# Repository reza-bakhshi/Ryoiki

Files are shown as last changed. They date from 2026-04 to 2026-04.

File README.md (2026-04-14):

# Ryoiki

⚠️ **THIS PROJECT IS UNDER ACTIVE DEVELOPMENT AND TESTING
DO NOT MANUFACTURE OR USE THE HARDWARE WITHOUT YOUR OWN VERIFICATION**

---

## Images

### TOP

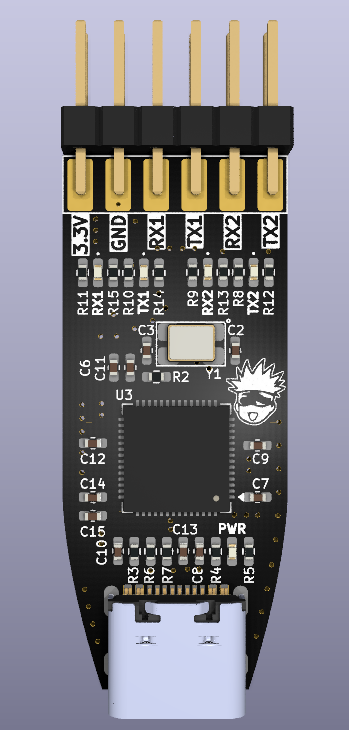
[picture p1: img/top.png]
top


### BOTTOM

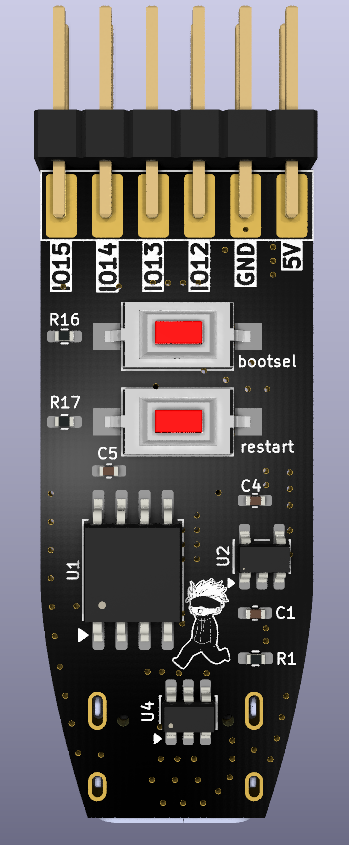
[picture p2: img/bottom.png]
bottom


---

## Overview

**Ryoiki** is an RP2040-based multi-purpose USB protocol bridge designed for embedded development workflows where USB ports are limited and multiple hardware interfaces are required.

This project is inspired by:

* BlueTag
* Bus Pirate
* pico-uart-bridge

The device is designed to:

* Bridge multiple protocols (UART / I²C / SPI → USB)
* Reduce the number of USB ports used
* Act as a compact RP2040 header-style board with limited pins when needed

---

## Project Goal

During embedded Linux development, using multiple USB-to-serial converters quickly consumes all available USB ports and creates cable clutter.

**Ryoiki** solves this by providing multiple interfaces over a single USB connection in a compact and flexible form factor.

---

## Current Status

| Interface | Status |
| --- | --- |
| UART | ✅ Working |
| I²C | 🚧 In development (currently disabled) |
| SPI | 🚧 In development (currently disabled) |

This is a prototype and both hardware and firmware are still under validation.

---

## Firmware

The current firmware is based on my fork of the pico-uart-bridge project.

When connected to a Linux system, the device enumerates as two independent CDC interfaces:

```text
/dev/ttyACM0  
/dev/ttyACM1
```

Each interface provides access to one UART channel.

### Features

* Auto-baudrate detection
* No manual baudrate configuration required
* Plug-and-play on Linux

---

## Hardware Design

The hardware is designed based on:

* RP2040 Zero form factor
* Official Raspberry Pi RP2040 hardware design guidelines

### Design Targets

* Compact size
* Low component count
* High flexibility for future features
* Header-style usability in external projects

### Hardware Features

* RP2040 microcontroller
* USB device interface
* Dual UART ports
* Dedicated **RX/TX status LEDs** for each UART

Designed with **KiCad**.

---

## Use Cases

* Embedded Linux development
* Multi-device serial debugging
* Compact USB lab tool
* Future multi-protocol debugging interface

---

## Future Plans

| Feature | Description | Status |
| --- | --- | --- |
| I²C Bridge | USB to I²C interface | 🚧 In development |
| SPI Bridge | USB to SPI interface | 🚧 In development |
| Multi-protocol Debug Mode | Bus Pirate / BlueTag-like functionality | 🧩 Planned |

---

## Development Notes

* Hardware revisions are expected
* Firmware is evolving rapidly
* Not production-ready

---

## Repository Structure

```text
/hardware   → KiCad design files  
/firmware   → RP2040 firmware  
/docs       → Documentation  
```

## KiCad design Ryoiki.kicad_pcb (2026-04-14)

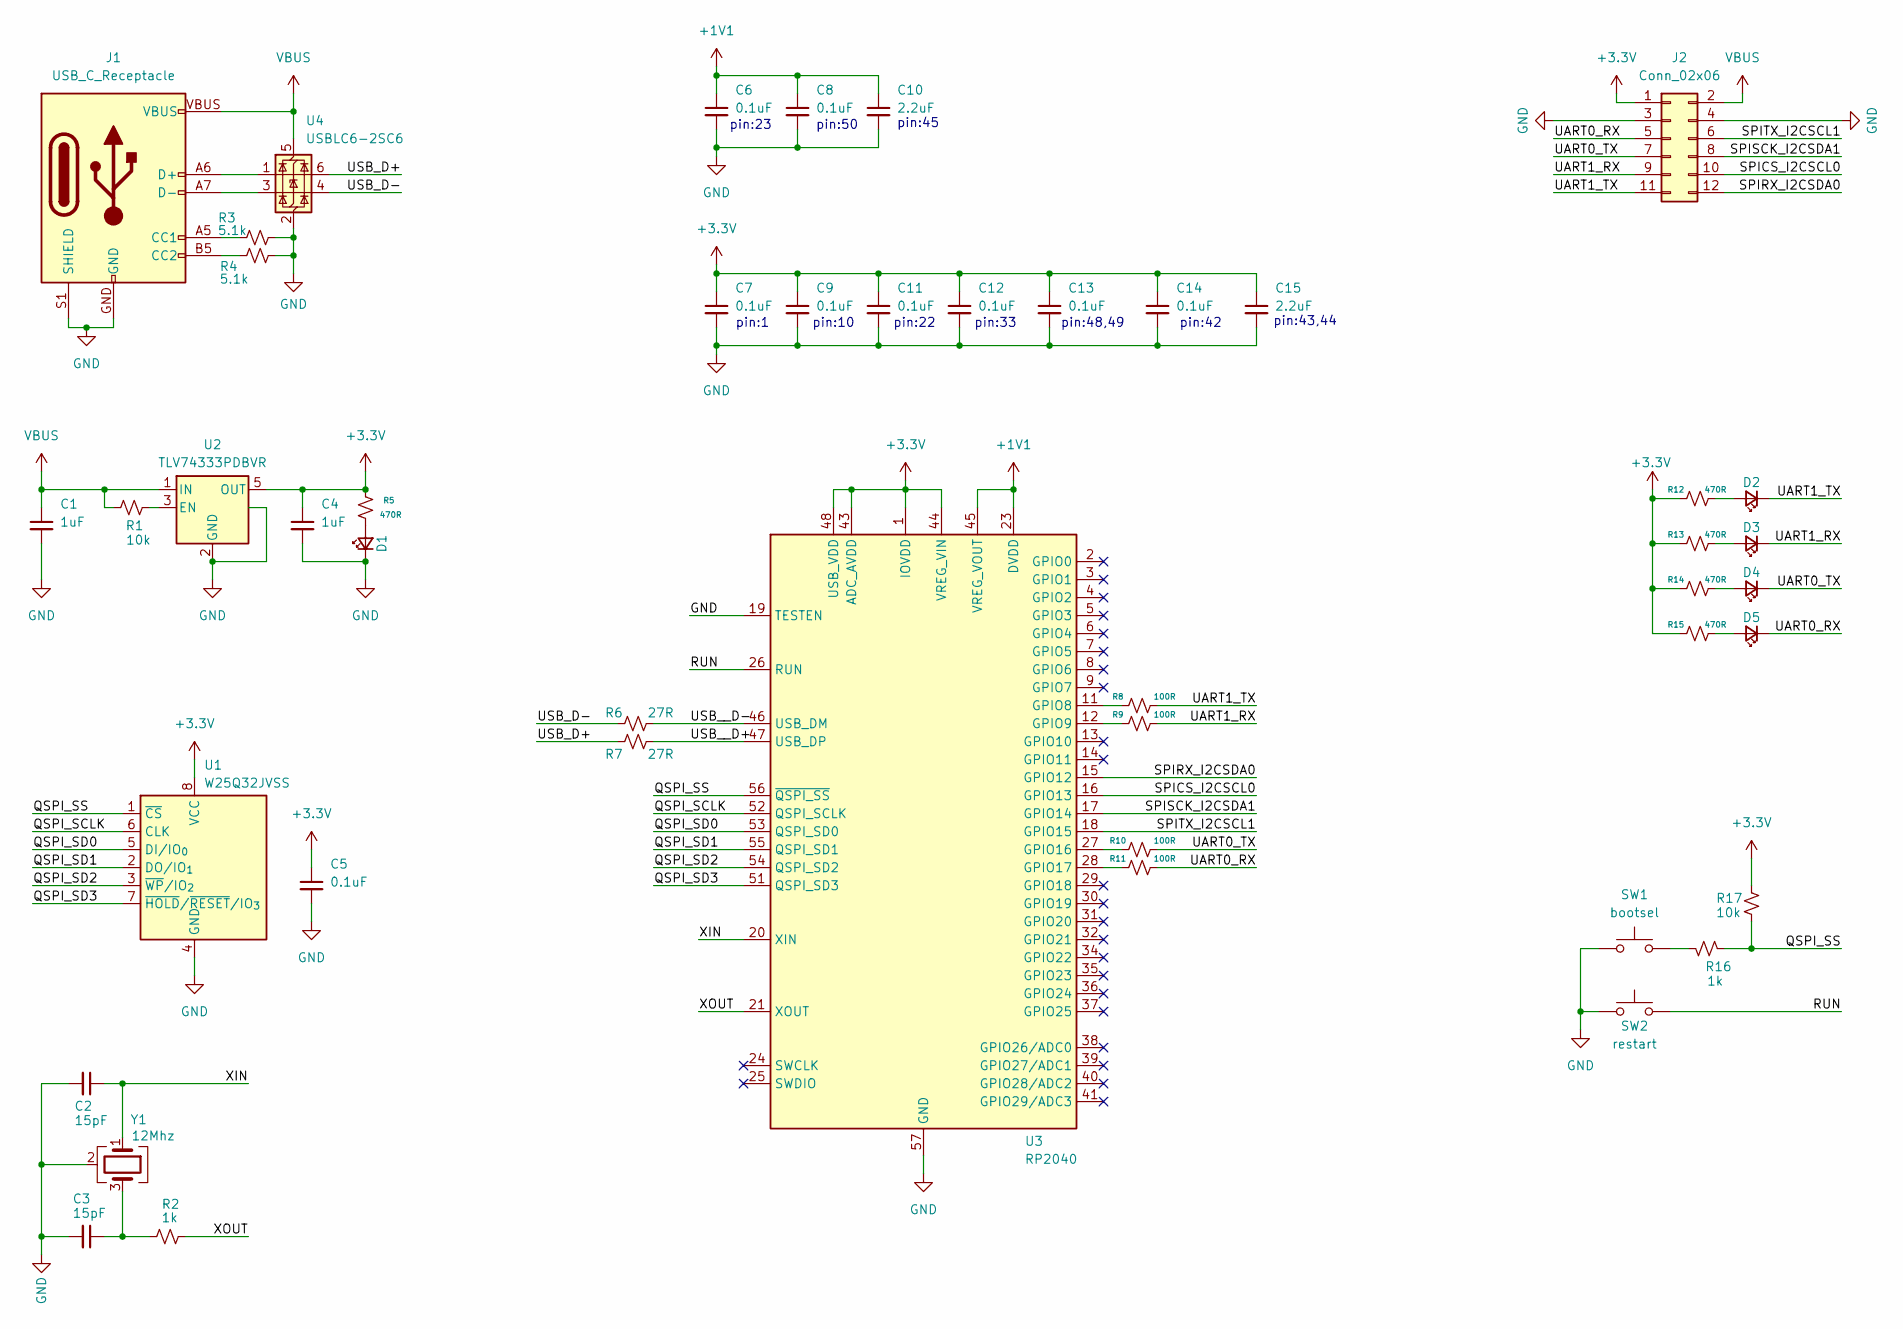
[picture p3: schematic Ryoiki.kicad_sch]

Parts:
C1, C4: 1uF; C_0402_1005Metric_Pad0.74x0.62mm_HandSolder; Voltage 25V
C2, C3: 15pF; C_0402_1005Metric_Pad0.74x0.62mm_HandSolder
C5, C6, C7, C8, C9, C11, C12, C13, C14: 0.1uF; C_0402_1005Metric_Pad0.74x0.62mm_HandSolder; Voltage 25V
C10, C15: 2.2uF; C_0402_1005Metric_Pad0.74x0.62mm_HandSolder; Voltage 25V
D1: PWR; LED_0402_1005Metric_Pad0.77x0.64mm_HandSolder
D2: TX2; LED_0402_1005Metric_Pad0.77x0.64mm_HandSolder
D3: RX2; LED_0402_1005Metric_Pad0.77x0.64mm_HandSolder
D4: TX1; LED_0402_1005Metric_Pad0.77x0.64mm_HandSolder
D5: RX1; LED_0402_1005Metric_Pad0.77x0.64mm_HandSolder
J1: USB_C_Receptacle; USB-C_16
J2: Conn_02x06; PinHeader_2x06_SMD_P2.54mm_Horizontal
R1, R17: 10k; R_0402_1005Metric_Pad0.72x0.64mm_HandSolder
R2, R16: 1k; R_0402_1005Metric_Pad0.72x0.64mm_HandSolder
R3, R4: 5.1k; R_0402_1005Metric_Pad0.72x0.64mm_HandSolder
R5, R12, R13, R14, R15: 470R; R_0402_1005Metric_Pad0.72x0.64mm_HandSolder
R6, R7: 27R; R_0402_1005Metric_Pad0.72x0.64mm_HandSolder
R8, R9, R10, R11: 100R; R_0402_1005Metric_Pad0.72x0.64mm_HandSolder
SW1: bootsel; SW_SPST_CK_RS282G05A3
SW2: restart; SW_SPST_CK_RS282G05A3
U1: W25Q32JVSS; SOIC-8_5.3x5.3mm_P1.27mm
U2: TLV74333PDBVR; SOT-23-5
U3: RP2040; QFN-56-1EP_7x7mm_P0.4mm_EP3.2x3.2mm
U4: USBLC6-2SC6; SOT-23-6
Y1: 12Mhz; Crystal_SMD_4Pin

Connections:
+1V1: C6.1, C8.1, C10.1, U3.23 (DVDD), U3.45 (VREG_VOUT), U3.50 (DVDD)
+3.3V: C4.1, C5.1, C7.1, C9.1, C11.1, C12.1, C13.1, C14.1, C15.1, J2.1, R5.1, R12.1, R13.1, R14.1, R15.1, R17.1, U1.8 (VCC), U2.5 (OUT), U3.1 (IOVDD), U3.10 (IOVDD), U3.22 (IOVDD), U3.33 (IOVDD), U3.42 (IOVDD), U3.43 (ADC_AVDD), U3.44 (VREG_VIN), U3.48 (USB_VDD), U3.49 (IOVDD)
/QSPI_SCLK: U1.6 (CLK), U3.52 (QSPI_SCLK)
/QSPI_SD0: U1.5 (DI/IO_{0}), U3.53 (QSPI_SD0)
/QSPI_SD1: U1.2 (DO/IO_{1}), U3.55 (QSPI_SD1)
/QSPI_SD2: U1.3 (~WP/IO_{2}), U3.54 (QSPI_SD2)
/QSPI_SD3: U1.7 (~HOLD/~RESET/IO_{3}), U3.51 (QSPI_SD3)
/QSPI_SS: R16.2, R17.2, U1.1 (~CS), U3.56 (~QSPI_SS)
/RUN: SW2.2, U3.26 (RUN)
/SPICS_I2CSCL0: J2.10, U3.16 (GPIO13)
/SPIRX_I2CSDA0: J2.12, U3.15 (GPIO12)
/SPISCK_I2CSDA1: J2.8, U3.17 (GPIO14)
/SPITX_I2CSCL1: J2.6, U3.18 (GPIO15)
/UART0_RX: D5.1 (K), J2.5, R11.2
/UART0_TX: D4.1 (K), J2.7, R10.2
/UART1_RX: D3.1 (K), J2.9, R9.2
/UART1_TX: D2.1 (K), J2.11, R8.2
/USB_D+: R7.1, U4.6 (I/O1)
/USB_D-: R6.1, U4.4 (I/O2)
/USB__D+: R7.2, U3.47 (USB_DP)
/USB__D-: R6.2, U3.46 (USB_DM)
/XIN: C2.1, U3.20 (XIN), Y1.1
/XOUT: R2.2, U3.21 (XOUT)
GND: C1.2, C2.2, C3.2, C4.2, C5.2, C6.2, C7.2, C8.2, C9.2, C10.2, C11.2, C12.2, C13.2, C14.2, C15.2, D1.1 (K), J1.GND, J1.S1 (SHIELD), J1.S2 (SHIELD), J1.S3 (SHIELD), J1.S4 (SHIELD), J2.3, J2.4, R3.2, R4.2, SW1.1, SW2.1, U1.4 (GND), U2.2 (GND), U2.4 (NC), U3.19 (TESTEN), U3.57 (GND), U4.2 (GND), Y1.2 (G), Y1.4 (G)
unnamed: C3.1, R2.1, Y1.3
unnamed: D1.2 (A), R5.2
unnamed: D2.2 (A), R12.2
unnamed: D3.2 (A), R13.2
unnamed: D4.2 (A), R14.2
unnamed: D5.2 (A), R15.2
unnamed: J1.A5 (CC1), R3.1
unnamed: J1.B5 (CC2), R4.1
unnamed: J1.A6 (D+), J1.B6 (D+), U4.1 (I/O1)
unnamed: J1.A7 (D-), J1.B7 (D-), U4.3 (I/O2)
unnamed: R16.1, SW1.2
unnamed: R1.1, U2.3 (EN)
unnamed: R8.1, U3.11 (GPIO8)
unnamed: R9.1, U3.12 (GPIO9)
unnamed: R10.1, U3.27 (GPIO16)
unnamed: R11.1, U3.28 (GPIO17)
VBUS: C1.1, J1.VBUS, J2.2, R1.2, U2.1 (IN), U4.5 (VBUS)

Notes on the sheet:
pin:42
pin:1
pin:23
pin:45
pin:50
pin:22
pin:48,49
pin:33
pin:43,44
pin:10

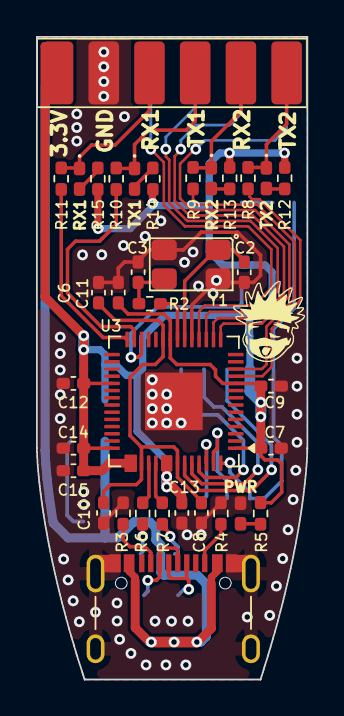
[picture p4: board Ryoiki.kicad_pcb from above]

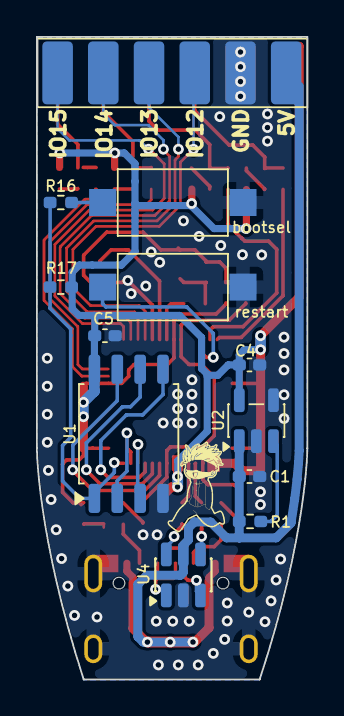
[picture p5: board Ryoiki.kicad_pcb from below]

Board: 2 copper layers, 15.0 x 35.7 mm, 46 parts (11 on the bottom side), 41 nets.

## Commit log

2026-02-20 Ryoiki Tenkai 🤞 - initial commit [V1.0]
    [Ryoiki.kicad_pcb, Ryoiki.kicad_sch]
2026-02-23 - Added ESD protection (USBLC6-2SC6) to the USB data lines and VBUS. - add more satoru gojo
    [Ryoiki.kicad_pcb, Ryoiki.kicad_sch]
2026-04-11 update gojo icons
    [Ryoiki.kicad_pcb]
2026-04-14 update from kicad v9 to v10
    [Ryoiki.kicad_pcb, Ryoiki.kicad_sch]
